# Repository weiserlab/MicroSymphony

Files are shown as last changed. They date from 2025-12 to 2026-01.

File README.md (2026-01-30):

# MicroSymphony
<a href="misc/stacked.svg">
  MicroSymphony stacked boards
</a>

MicroSymphony is a modular multi-microcontroller platform designed for **compute-first microwatt systems**. Instead of relying on a single MCU to multiplex sensing, computation, and communication, MicroSymphony physically distributes these roles across multiple ultra-low-power microcontrollers that operate concurrently while remaining power- and clock-isolated.

At its core, the platform enables predictable concurrency under tight energy budgets. Each board integrates multiple independent MCUs, a lightweight mechanism for programming them from a single host connection, and a inter-processor communication substrate built on shared non-volatile memory. This architecture avoids the timing conflicts, interrupt interference, and memory pressure inherent in monolithic single-MCU designs, while remaining simple enough for microwatt-class devices.

## Repository Structure

- [`hardware/`](https://github.com/weiserlab/MicroSymphony/tree/main/hardware)  
  Schematics, PCB designs, and platform documentation (under consturction) for the MicroSymphony multi-MCU platform.

- [`Vega_Bootloader/`](https://github.com/weiserlab/MicroSymphony/tree/main/Vega%20Bootloader#vega-bootloader)  
  The Vega programming framework, which repurposes a shared UART bus to enable low-latency programming of multiple microcontrollers from a single host interface. It supports both broadcast and individually addressed firmware updates without requiring per-MCU debug probes.

- [`IPC/`](https://github.com/weiserlab/MicroSymphony/tree/main/IPC#ipc)  
  The inter-processor communication layer that coordinates independent MCUs using a shared FRAM-based mailbox abstraction with explicit arbitration. This design provides deterministic, low-overhead communication suitable for intermittent and energy-constrained operation.

- [`Applications/`](https://github.com/weiserlab/MicroSymphony/tree/main/Applications)
  Applications designed using MicroSymphony framework. (Will be updated with more soon)

## Scope

This repository focuses on the **platform, programming, and communication mechanisms** required to build and experiment with multi-microcontroller systems at microwatt power levels. The work is under active development

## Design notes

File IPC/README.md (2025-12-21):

# IPC

Multi-MCU inter-process communication system using shared SPI FRAM with hardware-based lock arbitration.

## Features

- **Shared FRAM access**: Single external SPI FRAM shared among multiple MCUs
- **Hardware arbitration**: Dedicated REQ/GNT protocol ensures exclusive FRAM access
- **Mailbox-based messaging**: Fixed-size message slots with per-node ring buffers
- **Bulk transfers**: Efficient batch operations for sending multiple messages
- **Scalable architecture**: Supports 1 arbiter and multiple workers (tested upto 3 workers)

## File Structure

```
.
├── SPI_Arbitrar_5969/       # Arbiter (master) MCU code
│   ├── main.c               # Arbiter logic, REQ/GNT handling
│   ├── fram.c/h             # FRAM SPI driver (arbiter side)
│   ├── mailbox.c/h          # Mailbox management
│   ├── uart.c/h             # UART debug interface
│
└── SPI_Worker_5969/         # Worker node MCU code
    ├── main.c               # Worker logic, lock acquisition
    ├── fram.c/h             # FRAM SPI driver (worker side)
    ├── mailbox.c/h          # Mailbox operations
    └── uart.c/h             # UART debug interface
```

## Wiring and Connections

### MCU
- This wiring is for **MSP430FR5969**, pin mapping have to be changed for MSP430FR5949

### SPI Bus (UCB0) - Shared by All MCUs
| Signal | Pin  | Description |
|---|---|---|
| MOSI | P1.6 | Master Out Slave In |
| MISO | P1.7 | Master In Slave Out |
| SCK | P2.2 | SPI Clock |
| CS# | P1.5 | FRAM Chip Select |

### REQ/GNT Pairs (Arbiter ↔ Workers)

**Arbiter Pins:**

| Worker | REQ (Input) | GNT (I/O) | Description |
|---|---|---|---|
| Node 1 | P1.4 | P1.3 | Request/Grant for Node 1 |
| Node 2 | P1.2 | P3.0 | Request/Grant for Node 2 |
| Node 3 | P3.5 | P3.6 | Request/Grant for Node 3 |

**Worker Pins (same for all workers):**

| Signal | Pin  | Description |
|---|---|---|
| REQ | P1.4 | Request line to arbiter |
| GNT | P1.3 | Grant line from arbiter |

### Protocol
- Default state: Pull-down (logic 0)
- Signaling: Brief HIGH pulses
- Interrupts: Triggered on low→high edges
- Only one MCU accesses FRAM at a time, enforced by the lock protocol

## Usage

### Lock Management

```c
lock_acquire()
```
Requests and acquires exclusive access to the shared FRAM. Worker sends REQ pulse and waits for GNT from arbiter.

```c
lock_release()
```
Releases the FRAM lock so that other nodes can access it. Worker sends REQ pulse to signal release.

### Mailbox Operations

<a href="../misc/mailbox.svg">
  MicroSymphony mailbox layout
</a>

**All mailbox operations must be performed while holding the FRAM lock.**

```c
mailbox_send_msg(dest, src, buf, len)
```
Enqueues a single message of length `len` from `src` into the mailbox of node `dest`.
- `dest`: Destination node index (0-3)
- `src`: Source node ID
- `buf`: Message payload buffer
- `len`: Payload length (≤ 60 bytes)
- Returns: 1 on success, 0 on failure

```c
mailbox_send_bulk(dest, src, buf, total_len)
```
Sends bulk data from `src` to node `dest` using an optimized FRAM write.
- `dest`: Destination node index (0-3)
- `src`: Source node ID
- `buf`: Data buffer
- `total_len`: Total data length
- Returns: 1 on success, 0 on failure

```c
mailbox_recv_msg(id, src_out, len_out, buf)
```
Dequeues the next message for node `id` and returns its source and payload.
- `id`: This node's index
- `src_out`: Pointer to store source node ID
- `len_out`: Pointer to store payload length
- `buf`: Buffer to receive payload (≥ 60 bytes)
- Returns: 1 on success, 0 if mailbox empty

## Notes

- **FRAM Layout**: 4 mailboxes @ 20 kB each, starting at `0x01000`, `0x06000`, `0x0B000`, `0x10000`
- **Message Slots**: Fixed 64-byte slots (4-byte header + 60-byte payload max)
- **Notification Mechanism**: Global FRAM byte (`0x00010`) tracks which nodes have pending messages
- **Initialization**: Call `mailbox_init_layout()` once during system setup to initialize all mailbox descriptors
- **Node Configuration**: Workers must set `NODE_ID` (1-3) during compilation
- **UART Debug**: Both arbiter and workers support UART output on P2.0 (TX) / P2.1 (RX) for debugging

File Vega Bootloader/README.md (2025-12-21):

# Vega Bootloader

The **Vega Bootloader** is a custom bootloader designed as part of the **MicroSymphony** platform to enable broadcast-based firmware upgrades for multiple microcontrollers using a single programmer. This bootloader can be loaded onto MSP430-class microcontrollers, with code provided for MSP430FR5949/5969/5959. 

The bootloader is built on [MSP430FRBoot](https://www.ti.com/lit/an/slaa721e/slaa721e.pdf), TI's bootloader framework.

## Overview

In this system:
- **Target**: The microcontroller(s) that receive the bootloader and will be programmed over the multi-drop network
- **Host**: An external microcontroller (MSP430FR5969 LaunchPad) that serves as the programmer, flashing firmware to all connected targets simultaneously

<a href="../misc/bootloader_flow.svg">
  VEGA Bootloader Flow
</a>

## Features

- **GPIO-based boot entry**: Boot pin based entry mechanism into boot mode on reset
- **Unique addressing**: Each microcontroller has an address in format `xxxyyyy` where:
  - `xxx` = board/platform number (one-hot encoded)
  - `yyyy` = microcontroller number (one-hot encoded)
- **Multi-drop UART protocol**: Enables broadcasting to multiple targets
- **Simultaneous flashing**: Flash multiple microcontrollers at once (tested up to 12 devices)
- **Built on MSP430FRBoot**: Leverages TI's proven bootloader framework

## Prerequisites

- Code Composer Studio (CCS) IDE
- MSP430FR5969 LaunchPad (for Host)
- MSP430FR5949/5969/5959 targets
- Python 3.6+ with `pyserial` library

## Repository Structure

```
.
├── Host-parallel/              # Host MSP430FR5969 project (CCS project)
├── MSPFR5949/
│   ├── App1_5949/             # Example application for MSP430FR5949 (CCS project)
│   └── Slave-parallel_5949/   # Bootloader for MSP430FR5949 (CCS project)
├── send2MSP-parallel.py       # Python script to send app image to host
└── README.md                  # This file
```

## Hardware Connections

### Host MSP (MSP430FR5969 LaunchPad)
- **P2.6** → RX (UART receive)
- **P2.5** → TX (UART transmit)
- **P3.0** → RST (reset line to all targets)
- **P1.3** → Boot pin (connects to all targets)

### Target MSP (MSP430FR5949/5969/5959)
- **P2.6** → RX (UART receive)
- **P2.5** → TX (UART transmit)
- **RST** → RST (shared reset line from host)
- **P1.3** → Boot pin (from host's P1.3)

All devices (host and targets) must share a common ground connection.

## Getting Started

<a href="../misc/flashing_flow.svg">
  VEGA Bootloader Flow
</a>

### Step 1: Flash the Bootloader to Target Devices

1. **Configure the bootloader** for each target:
   - Open the appropriate `Slave-parallel_xxxx` project for your target MCU in CCS
   - Edit `TI_MSPBoot_Config.h` to set:
     - `SLAVE_ADDRESS_MASK`: Unique address for this target (e.g., `BIT0`, `BIT1`, `BIT2`, `BIT3`)
     - `BOARD_ADDRESS_MASK`: Board/platform number (e.g., `BIT4`, `BIT5`, `BIT6`)
     - `HW_ENTRY_CONDITION`: Boot pin configuration (default: `P1IN & BIT3`)
   
   **Important**: Ensure no two targets have the same address combination! If addresses conflict, multiple devices may respond simultaneously, causing communication errors and flash failures.

2. **Build and flash** the bootloader project to each target microcontroller using CCS or a programmer

3. **Repeat** for all target devices, changing the address for each

### Step 2: Prepare Your Application

1. **Merge your application code** into the appropriate `App1_xxxx` project for your target MCU

2. **Configure the linker file**:
   - The App project should use the `lnk_App.cmd` linker file
   - This ensures the application is placed in the correct memory region (not overwriting the bootloader)

3. **Build the application** in CCS:
   - Build the project to generate the output files
   - Locate the generated `.txt` file (TI-TXT format) in the output directory

4. **Note the TI-TXT file location** - you'll need this for the Python script

### Step 3: Flash the Host Programmer

1. **Open** the `Host-parallel` project in CCS

2. **Verify memory addresses** in `main.c` match your target device (see [Linker File Generation](#linker-file-generation) if adapting to other MSP variants)

3. **Build and flash** the Host project to the MSP430FR5969 LaunchPad

### Step 4: Program Targets via Host

1. **Connect hardware**:
   - Connect the Host MSP430FR5969 LaunchPad to your PC via USB
   - Ensure all target devices are connected to the host as described in [Hardware Connections](#hardware-connections)

2. **Configure the Python script**:
   - Open `send2MSP-parallel.py`
   - Set `port_path` to match your serial port:
     - Linux: `/dev/ttyACM0`, `/dev/ttyACM1`, or `/dev/ttyUSB0`
     - Windows: `COM3`, `COM4`, etc.
     - macOS: `/dev/cu.usbmodem*` (e.g., `/dev/cu.usbmodem14201`)
   
   ```python
   port_path = "/dev/ttyACM0"  # Change to your port
   ```

3. **Run the flashing script**:
   ```bash
   python send2MSP-parallel.py
   ```

4. The script will:
   - Parse the TI-TXT file
   - Frame the data into packets
   - Send the firmware image to the host
   - The host will broadcast to all connected targets
   - Targets matching the configured addresses will be programmed

## Troubleshooting

- **Targets not responding**: Verify all addresses are unique and connections are correct
- **Flash verification fails**: Ensure the application doesn't overlap with bootloader memory
- **Serial port errors**: Check port permissions and that the correct port is specified
- **CRC mismatch**: Regenerate the TI-TXT file and ensure no corruption during transfer

## References

- [MSP430FRBoot Application Note (SLAA721E)](https://www.ti.com/lit/an/slaa721e/slaa721e.pdf)
- [MSP430FR5xx and MSP430FR6xx Family User's Guide](https://www.ti.com/lit/ug/slau367p/slau367p.pdf)
- Code Composer Studio: [https://www.ti.com/tool/CCSTUDIO](https://www.ti.com/tool/CCSTUDIO)

See individual source files for license information. This project builds upon TI's MSP430FRBoot framework.

This is part of the MicroSymphony platform research project. For questions or contributions, please open an issue.

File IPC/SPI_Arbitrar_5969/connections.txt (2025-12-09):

SPI: UCB0 on all MCUs (arbiter + workers)

MOSI: P1.6

MISO: P1.7

SCK: P2.2

FRAM CS: moved to P2.3 (to free P3.0 for Node2 GNT as you requested).

If your hardware still uses P3.0 for CS, either rewire or revert that macro yourself.

REQ/GNT logic:

Default state: pull-down, logic 0.

Pulses: drive HIGH briefly.

Interrupts: edges are low→high.

Pin mapping on arbiter (master):

Node 1:

REQ1: P1.4 (input, pulldown, interrupt)

GNT1: P1.3 (I/O, pulldown, interrupt for reset)

Node 2:

REQ2: P1.2 (input, pulldown, interrupt)

GNT2: P3.0 (I/O, pulldown, interrupt for reset)

Node 3:

REQ3: P3.5 (input, pulldown, interrupt)

GNT3: P3.6 (I/O, pulldown, interrupt for reset)

On each worker, the local pins to arbiter are always:

REQ: P1.4

GNT: P1.3

One “notification byte” in FRAM:

Address chosen as FRAM_NOTIFY_ADDR 0x0000.

Bit k set → “node with index k has new messages”.

Mapping from bit index → node ID is done in arbiter.

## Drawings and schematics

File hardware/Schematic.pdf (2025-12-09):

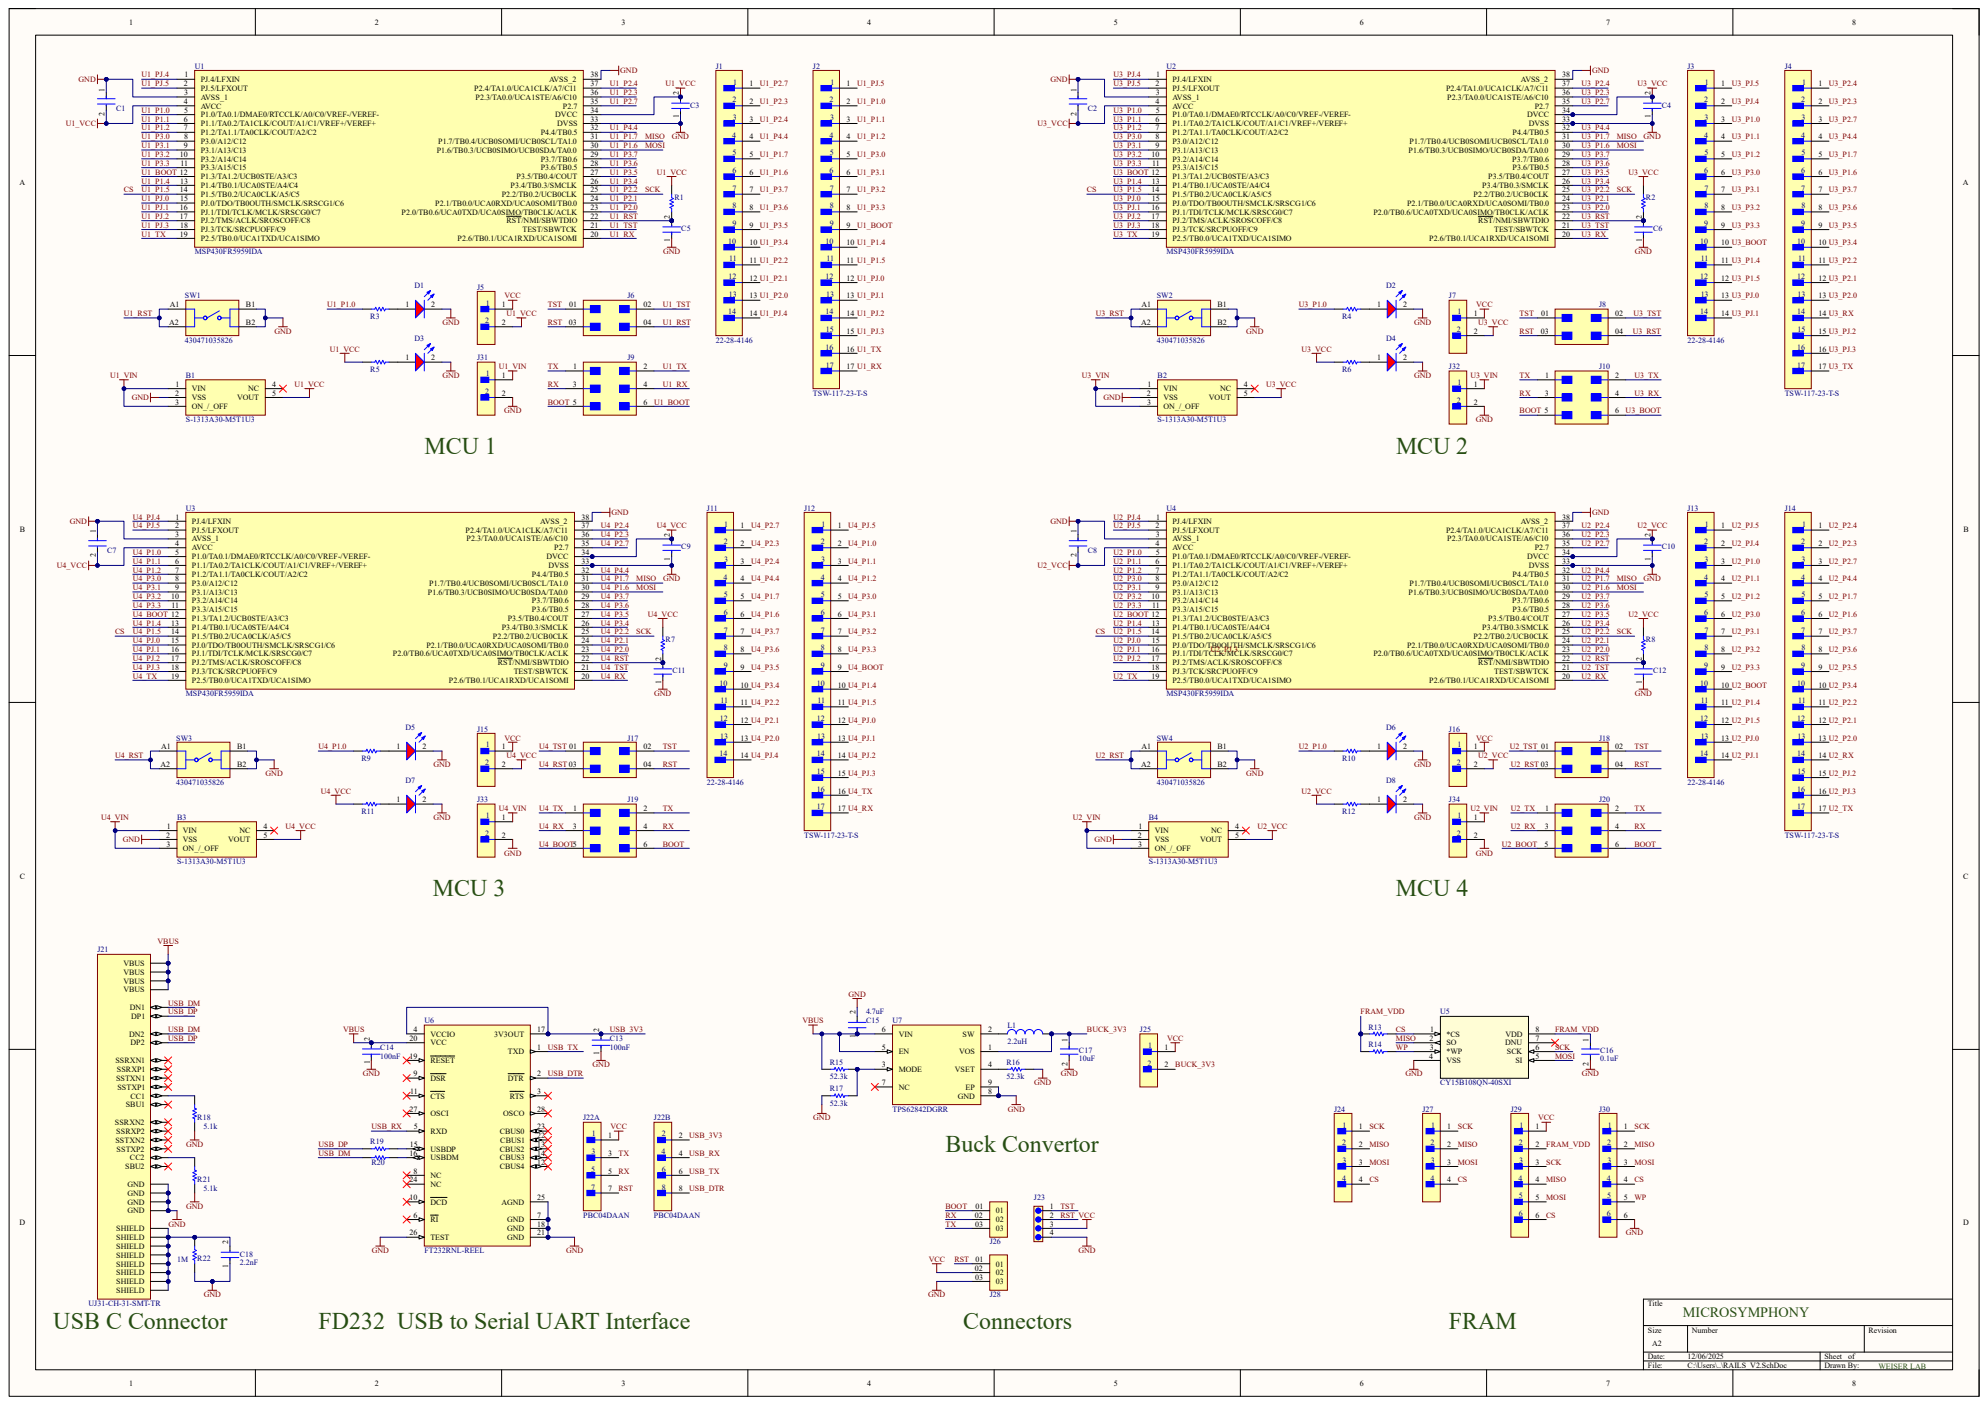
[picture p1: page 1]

P1.5/TB0.2/UCA0CLK/A5/C5 14
PJ.0/TDO/TB0OUTH/SMCLK/SRSCG1/C6 15
PJ.1/TDI/TCLK/MCLK/SRSCG0/C7 16
PJ.2/TMS/ACLK/SROSCOFF/C8 17

PJ.3/TCK/SRCPUOFF/C9 18

FD232 USB to Serial UART Interface

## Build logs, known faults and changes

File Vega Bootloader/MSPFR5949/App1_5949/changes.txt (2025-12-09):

- Folder properties -> General -> Device variant -> __MSP430FR5959__
- replace .cmd file generated from Utilities/linkerGen in Config_App
- remove .cmd in / if genearted to remove 100+ errors during compilation

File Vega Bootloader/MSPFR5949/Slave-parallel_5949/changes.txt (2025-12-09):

- add 38400 baud

Linkers generated on 3/10/2025:

output_filename:  lnk_fr5949_single_2k_xxx.cmd
lnk_filename:  lnk_msp430fr5949.cmd
boot_size:  0xc00
Device name:  msp430fr5949
2025-10-03

App start:     0x4400
appl_end_addr: 0xf3ff
Flex start:    0x10000
flex_end_addr: 0xf400
vector_addr:      0xf390
The two linker files for boot side and application side are generated!

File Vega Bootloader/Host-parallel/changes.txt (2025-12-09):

in main.c:
change static uint32_t App_EndAddress_Upper = 0x13FFF - 8; // -8 for MSP5959

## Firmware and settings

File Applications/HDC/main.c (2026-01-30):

#include <msp430.h>
#include <stdint.h>
#include <string.h>

#include "uart.h"
#include "fram.h"
#include "mailbox.h"
#include "worker.h"
#include "hypercam_full_256.h"     // <--- 256/512/768 HV table

/* ================================================================
 * CONFIGURATION
 * ================================================================ */

/* Total cooperating MCUs */
#define N_NODES       3u      /* change to 3 or 4 later */

/* Node ID: 0 .. N_NODES-1 (set individually per build) */
#define NODE_ID       0u

/* MNIST image size */
#define IMG_W         28u
#define IMG_H         28u
#define NUM_PIXELS    (IMG_W * IMG_H)

/* Bits per node slice */
#define BITS_PER_NODE   (HV_DIM_BITS / N_NODES)
#define WORDS_PER_NODE  (BITS_PER_NODE / 32u)
#define BYTES_PER_NODE  (BITS_PER_NODE / 8u)

/* Accumulator type */
typedef int16_t acc_t;

// declare external HV tables
extern const uint32_t X0_words[WORDS_PER_HV];
extern const uint32_t value_hv[256][WORDS_PER_HV];
extern const uint32_t class_hv[NUM_CLASSES][WORDS_PER_HV];
extern const uint8_t sample_image[NUM_PIXELS];
// extern

uint32_t  e1, e2, e3;


void timer_start(void){
    TA0CTL = TASSEL__SMCLK | MC__CONTINUOUS | TACLR | ID__8;  // SMCLK/8
    TA0EX0 = TAIDEX_7;   
}


/* ================================================================
 * COMMUNICATION STUBS (YOU FILL THESE)
 * ================================================================ */

/* Now takes uint8_t* slice (BYTES_PER_NODE bytes) */
static void send_hv_slice_to_node0(const uint8_t *slice)
{
    /* TODO: send BYTES_PER_NODE bytes to node 0 (SPI/UART/mailbox) */
    lock_acquire();
    uint8_t resp=0;
    resp = mailbox_send_bulk(0u, NODE_ID, slice, BYTES_PER_NODE);
    // __delay_cycles(40000); // small delay (switch to level based)
    // uart0_println("Send failed");
    lock_release();
    if (!resp) {P4OUT |= BIT6; P1OUT |= BIT0;}

}

#if NODE_ID == 0
/* Now receives uint8_t* slice (BYTES_PER_NODE bytes) */
static uint8_t recv_hv_slice_from_node(uint8_t *src, uint8_t *dst)
{
    /* TODO: receive BYTES_PER_NODE bytes from node src */
    lock_acquire();
    uint16_t len = 0u;
    uint8_t resp = 1;
    resp = mailbox_recv_msg(0u, src, &len, dst);

    lock_release();
    return resp;
}
#endif


/* ================================================================
 * BIT HELPERS (LOCAL SLICE ONLY)
 * ================================================================ */

static uint8_t get_bit(const uint32_t *words, uint16_t bit)
{
    uint16_t w = bit / 32u;
    uint16_t b = bit % 32u;
    return (words[w] >> b) & 1u;
}

/* Rotate the FULL HV (all WORDS_PER_HV words) left by 1 bit.
 * This matches the Python / training rotation, independent of node split.
 */
static void rotate_left1_full(uint32_t *words)
{
    uint32_t carry = 0, next = 0;
    uint16_t i;
    for (i = 0; i < WORDS_PER_HV; i++)
    {
        next = (words[i] >> 31) & 1u;
        words[i] = (words[i] << 1) | carry;
        carry = next;
    }
    /* wrap-around bit */
    if (carry)
        words[0] |= 1u;
}


/* ================================================================
 * GET GLOBAL SLICE OFFSET FOR THIS NODE
 * ================================================================ */

static inline uint16_t global_bit_offset(void)
{
    return NODE_ID * BITS_PER_NODE;
}


/* ================================================================
 * ENCODING (HV-SPLIT)
 * ================================================================ */

/* slice_out is now uint8_t*, length BYTES_PER_NODE. */
static void encode_image_slice(const uint8_t *img,
                               uint8_t *slice_out)
{
    acc_t  acc[BITS_PER_NODE];
    /* full position HV for global rotation */
    uint32_t pos_full[WORDS_PER_HV];
    /* this node's bound slice */
    uint32_t bound[WORDS_PER_NODE];

    uint16_t i, b, k;

    // uart0_println("Encoding image slice...");

    // uart0_println("1...");
    // uart0_println("Clearing accumulator...");
    /* 1. Clear accumulator */
    for (i = 0; i < BITS_PER_NODE; i++)
        acc[i] = 0;


    /* 2. Initialize FULL position HV:
     *    Copy entire X0_words (global HV), not just this node's slice.
     */
    for (i = 0; i < WORDS_PER_HV; i++)
        pos_full[i] = X0_words[i];

    // uart0_println("Position HV full initialized.");
    /* Node's slice word offset in the full HV */
    uint16_t off = global_bit_offset() / 32u;   // word offset

    /* 3. Process each pixel */
    for (k = 0; k < NUM_PIXELS; k++)
    {
        // uart0_println("Processing pixel:");
        // uart0_print_uint(k);
        // uart0_println("");
        uint8_t v = img[k];  /* pixel 0..255 */

        /* Slice of value HV for this pixel:
         * value_hv[v] is full HV; we take this node's slice.
         * Slice of position HV for this pixel:
         * pos_full is full HV; we take this node's slice.
         */
        for (i = 0; i < WORDS_PER_NODE; i++)
            bound[i] = pos_full[off + i] ^ value_hv[v][off + i];

        /* Update acc */
        for (b = 0; b < BITS_PER_NODE; b++)
        {
            uint8_t bit = get_bit(bound, b);
            acc[b] += (bit ? 1 : -1);
        }

        /* Permute FULL position HV */
        rotate_left1_full(pos_full);
    }

    // uart0_println("Finalizing slice...");
    /* 4. Majority vote → slice_out (byte-packed) */
    for (i = 0; i < BYTES_PER_NODE; i++)
        slice_out[i] = 0;

    // uart0_println("Performing majority vote...");
    for (b = 0; b < BITS_PER_NODE; b++)
    {
        uint8_t bit = (acc[b] > 0);
        if (bit) {
            /* bit b → byte index = b/8, bit position = b%8 (LSB-first) */
            uint16_t byte_idx = b >> 3;
            uint8_t bit_pos = b & 7u;
            slice_out[byte_idx] |= (uint8_t)(1u << bit_pos);
        }
    }
}


/* ================================================================
 * NODE 0: COLLECT SLICES, FORM FINAL HV, CLASSIFY
 * ================================================================ */

#if NODE_ID == 0
static uint32_t img_hv_full[WORDS_PER_HV];

/* Now takes uint8_t* slice (BYTES_PER_NODE bytes) */
static void combine_slice(uint8_t src, const uint8_t *slice)
{
    /* dst byte offset in full HV */
    uint16_t byte_off = (uint16_t)(BYTES_PER_NODE * src);

    /* Copy raw bytes into img_hv_full (reinterpret as uint8_t*) */
    uint8_t *dst_bytes = (uint8_t *)img_hv_full;

    uint16_t i;
    for (i = 0; i < BYTES_PER_NODE; i++) {
        dst_bytes[byte_off + i] = slice[i];
    }
}

static uint8_t classify_image(void)
{
    /* Full-HV Hamming classification using class_hv[][] */

    uint32_t best = UINT32_MAX;
    uint8_t best_c = 0;

    uint8_t c;
    uint16_t i;

    for (c = 0; c < NUM_CLASSES; c++) {
        uint32_t dist = 0;
        for (i = 0; i < WORDS_PER_HV; i++) {
            uint32_t x = img_hv_full[i] ^ class_hv[c][i];

            /* 32-bit SWAR popcount (portable, efficient on MSP430 GCC) */
            x = x - ((x >> 1) & 0x55555555u);
            x = (x & 0x33333333u) + ((x >> 2) & 0x33333333u);
            uint32_t pc = (((x + (x >> 4)) & 0x0F0F0F0Fu) * 0x01010101u) >> 24;

            dist += pc;
        }
        if (dist < best) {
            best = dist;
            best_c = c;
        }
    }

    return best_c;
}
#endif


/* ================================================================
 * MAIN PROCESSING
 * ================================================================ */

// static uint8_t image_buf[NUM_PIXELS];   // Fill this with your MNIST image

static void node_run(void)
{
    uint8_t my_slice[BYTES_PER_NODE];

    /* image already loaded*/

    /* Compute this node's slice */
    // uart0_println("Computing node slice...");
    encode_image_slice(sample_image, my_slice);
    // uart0_println("Image slice encoded.");

#if NODE_ID == 0
    /* Root node keeps its own slice */
    combine_slice(0, my_slice);

    uint8_t src=0;
    uint8_t counter = 0;

    
    // uart0_println("Waiting for slice...");
    timer_start();
    e1 = TA0R;
    /* For N_NODES == 1 this loop is skipped (no remote nodes). */
    
    while (counter < (uint8_t)(N_NODES - 1u))
    {

        if (!recv_hv_slice_from_node(&src, my_slice)) {
            /* No message yet; you can spin, sleep, or just retry */
            __delay_cycles(500000u);
            continue;
        }

        /* Expect slices from nodes 1..N_NODES-1 */
        if (src != 0u && src < N_NODES) {
            // uart0_print("Received slice from node ");
            // uart0_print_uint(src);
            // // print the slice for debugging
            // uint8_t i;
            // for (i = 0; i < BYTES_PER_NODE; i++) {
            //     uart0_print_uint(my_slice[i]);
            //     uart0_print(" ");
            // }
            // uart0_println("");

            combine_slice(src, my_slice);
            counter++;
        } else {
            // uart0_print("Unexpected src=");
            // uart0_print_uint(src);
            // uart0_println("");
            ;
        }

        // __delay_cycles(16000000u);
    }

    e1 = TA0R - e1;
    /* Now img_hv_full[] contains the full HV_DIM_BITS final HV */

    timer_start();
    e2 = TA0R;
    uint8_t predicted = classify_image();
    e2 = TA0R - e2;

    // uart0_print("Predicted class: ");
    // uart0_print_uint(predicted);
    // uart0_println("");

    // uart0_print("Communication time (microseconds): ");
    // uart0_print_uint(e1*8u);
    // uart0_println("");

    // uart0_print("Classification time (microseconds): ");
    // uart0_print_uint(e2*8u);
    // uart0_println("");


#else
    /* Non-root nodes send their slice to node 0 */
    // uart0_println("Sending slice to node 0...");
    send_hv_slice_to_node0(my_slice);
    // uart0_print("Slice sent to node 0 from node ");
    // uart0_print_uint(NODE_ID);
    // uart0_println("");

#endif
    // spi_deinit();  // optional: free SPI if not needed anymore

}


/* ================================================================
 * MSP430 MAIN
 * ================================================================ */

int main(void)
{


    WDTCTL = WDTPW | WDTHOLD;

    /* TODO: clock / UART / SPI init */
    clock_init_8mhz();
    // uart0_init();
    node_gpio_init();


    PM5CTL0 &= ~LOCKLPM5;   // Disable the GPIO power-on default high-impedance mode

    spi_init();
    /* Reset pulse to arbiter (inform it we may have reset) */
    node_pulse_reset_on_gnt();


    P1OUT &= ~BIT0;
    P4OUT |= BIT6;


    __bis_SR_register(GIE);

    // uart0_println("HyperCam HDC Node Starting...");

    node_run();
    __bis_SR_register(LPM0_bits | GIE);
    
}

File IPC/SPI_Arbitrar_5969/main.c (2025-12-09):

// ======================= Arbiter (Master) =======================
//                   MSP430FR5969 (Arbiter)
//                 ---------------------------
//            /|\ |                       XIN|-
//             |  |                           | 32 kHz Crystal (optional)
//             ---|RST                    XOUT|-
//                |                           |
//                |                       P2.0|-> UART TX  (UCA0TXD, to USB-UART / PC)
//                |                       P2.1|<- UART RX  (UCA0RXD, from USB-UART / PC)
//                |                           |
//                |                       P1.6|-> FRAM SI   (UCB0SIMO, MOSI)
//                |                       P1.7|<- FRAM SO   (UCB0SOMI, MISO)
//                |                       P2.2|-> FRAM SCK  (UCB0CLK)
//                |                       P1.5|-> FRAM CS#  (chip select, active low)
//                |                           |
//                |                       P1.4|<- REQ1      (Node1 -> Arbiter, request)
//                |                       P1.3|<-> GNT1     (Arbiter <-> Node1, grant / reset)
//                |                       P1.2|<- REQ2      (Node2 -> Arbiter, request)
//                |                       P3.0|<-> GNT2     (Arbiter <-> Node2, grant / reset)
//                |                       P3.5|<- REQ3      (Node3 -> Arbiter, request)
//                |                       P3.6|<-> GNT3     (Arbiter <-> Node3, grant / reset)
//                |                           |
//                |                       P1.0|-> LED (activity / REQ seen)
//                |                       P4.6|-> LED (FRAM bus owned by some node)
//                |                           |
//               GND|---------------------------

#include <msp430.h>
#include <stdint.h>
#include "fram.h"
#include "mailbox.h"
#include "uart.h"

/* Arbiter supports 3 physical nodes for now */
#define NUM_NODES    3u

#define NODE1_ID     1u
#define NODE2_ID     2u
#define NODE3_ID     3u

/* REQ pins on arbiter */
#define N1_REQ_P1_PIN   BIT4      /* P1.4 */
#define N2_REQ_P1_PIN   BIT2      /* P1.2 */
#define N3_REQ_P3_PIN   BIT5      /* P3.5 */

/* GNT pins on arbiter */
#define N1_GNT_P1_PIN   BIT3      /* P1.3 */
#define N2_GNT_P3_PIN   BIT0      /* P3.0 */
#define N3_GNT_P3_PIN   BIT6      /* P3.6 */


/* ---- Clock ---- */

static void clock_init_8mhz(void)
{
    CSCTL0_H = CSKEY >> 8;
    CSCTL1   = DCOFSEL_6;
    CSCTL2   = SELS__DCOCLK | SELM__DCOCLK;
    CSCTL3   = DIVS__1 | DIVM__1;
    CSCTL0_H = 0;
}

/* ---- Globals ---- */

/* 0   = no one holds bus
 * 1..3 = node ID currently owning SPI/FRAM bus
 */
static volatile uint8_t g_lock_holder     = 0u;

/* Pending REQ events encoded as bits 0..(NUM_NODES-1) */
static volatile uint8_t g_req_event_mask  = 0u;

/* FCFS queue */
static volatile uint8_t g_queue[NUM_NODES];
static volatile uint8_t g_q_len           = 0u;

/* Need to schedule */
static volatile uint8_t g_need_schedule   = 0u;

/* ---- Queue helpers ---- */

static uint8_t index_to_node_id(uint8_t idx)
{
    if (idx == 0u) return NODE1_ID;
    if (idx == 1u) return NODE2_ID;
    if (idx == 2u) return NODE3_ID;
    return 0u;
}

static uint8_t queue_contains(uint8_t node_id)
{
    volatile uint8_t i;

    for (i = 0u; i < g_q_len; i++) {
        if (g_queue[i] == node_id) {
            return 1u;
        }
    }
    return 0u;
}

static void queue_push(uint8_t node_id)
{
    if (g_q_len >= NUM_NODES) {
        return;
    }
    if (queue_contains(node_id) != 0u) {
        return;
    }
    g_queue[g_q_len] = node_id;
    g_q_len++;
}

static uint8_t queue_pop(void)
{
    uint8_t i;
    uint8_t first;

    if (g_q_len == 0u) {
        return 0u;
    }

    first = g_queue[0];
    for (i = 1u; i < g_q_len; i++) {
        g_queue[i - 1u] = g_queue[i];
    }
    g_q_len--;

    return first;
}

static void queue_remove(uint8_t node_id)
{
    uint8_t i;
    uint8_t j = 0u;

    for (i = 0u; i < g_q_len; i++) {
        if (g_queue[i] != node_id) {
            g_queue[j] = g_queue[i];
            j++;
        }
    }
    g_q_len = j;
}

/* ---- GPIO init ---- */

static void arbiter_gpio_init(void)
{
    /* Port 1: N1_REQ=P1.4, N2_REQ=P1.2, N1_GNT=P1.3 */
    P1SEL0 &= ~(N1_REQ_P1_PIN | N2_REQ_P1_PIN | N1_GNT_P1_PIN);
    P1SEL1 &= ~(N1_REQ_P1_PIN | N2_REQ_P1_PIN | N1_GNT_P1_PIN);

    /* REQ inputs, pulldown, rising edge interrupt */
    P1DIR &= ~(N1_REQ_P1_PIN | N2_REQ_P1_PIN);
    P1REN |= (N1_REQ_P1_PIN | N2_REQ_P1_PIN);
    P1OUT &= ~(N1_REQ_P1_PIN | N2_REQ_P1_PIN);

    P1IES &= ~(N1_REQ_P1_PIN | N2_REQ_P1_PIN);
    P1IFG &= ~(N1_REQ_P1_PIN | N2_REQ_P1_PIN);
    P1IE  |= (N1_REQ_P1_PIN | N2_REQ_P1_PIN);

    /* GNT1 input, pulldown, rising edge for reset */
    P1DIR &= ~N1_GNT_P1_PIN;
    P1REN |= N1_GNT_P1_PIN;
    P1OUT &= ~N1_GNT_P1_PIN;
    
    P1IES &= ~N1_GNT_P1_PIN;
    P1IFG &= ~N1_GNT_P1_PIN;
    P1IE  |= N1_GNT_P1_PIN;

    /* Port 3: N3_REQ=P3.5, N2_GNT=P3.0, N3_GNT=P3.6 */
    P3SEL0 &= ~(N3_REQ_P3_PIN | N2_GNT_P3_PIN | N3_GNT_P3_PIN);
    P3SEL1 &= ~(N3_REQ_P3_PIN | N2_GNT_P3_PIN | N3_GNT_P3_PIN);

    /* REQ3 */
    P3DIR &= ~N3_REQ_P3_PIN;
    P3REN |= N3_REQ_P3_PIN;
    P3OUT &= ~N3_REQ_P3_PIN;
    
    P3IES &= ~N3_REQ_P3_PIN;
    P3IFG &= ~N3_REQ_P3_PIN;
    P3IE  |= N3_REQ_P3_PIN;

    /* GNT2, GNT3 inputs with pulldown, rising edge for reset */
    P3DIR &= ~(N2_GNT_P3_PIN | N3_GNT_P3_PIN);
    P3REN |= (N2_GNT_P3_PIN | N3_GNT_P3_PIN);
    P3OUT &= ~(N2_GNT_P3_PIN | N3_GNT_P3_PIN);

    P3IES &= ~(N2_GNT_P3_PIN | N3_GNT_P3_PIN);
    P3IFG &= ~(N2_GNT_P3_PIN | N3_GNT_P3_PIN);
    P3IE  |= (N2_GNT_P3_PIN | N3_GNT_P3_PIN);

    /* LEDs */
    P1DIR |= BIT0;
    P4DIR |= BIT6;
}

/* ---- GNT pulses ---- */

static void gnt_pulse_node(uint8_t node_id)
{
    volatile uint8_t *pdir;
    volatile uint8_t *pout;
    uint8_t port_bit;

    if (node_id == NODE1_ID) {
        pdir     = &P1DIR;
        pout     = &P1OUT;
        port_bit = N1_GNT_P1_PIN;
    } else if (node_id == NODE2_ID) {
        pdir     = &P3DIR;
        pout     = &P3OUT;
        port_bit = N2_GNT_P3_PIN;
    } else if (node_id == NODE3_ID) {
        pdir     = &P3DIR;
        pout     = &P3OUT;
        port_bit = N3_GNT_P3_PIN;
    } else {
        return;
    }

    /* Disable reset interrupt on this pin during pulse */
    if (node_id == NODE1_ID) {
        P1IE  &= (uint8_t)~port_bit;
        P1IFG &= (uint8_t)~port_bit;
    } else {
        P3IE  &= (uint8_t)~port_bit;
        P3IFG &= (uint8_t)~port_bit;
    }

    *pdir |=  port_bit;
    *pout |=  port_bit;
    __delay_cycles(50u);
    *pout &= (uint8_t)~port_bit;
    *pdir &= (uint8_t)~port_bit;

    if (node_id == NODE1_ID) {
        P1IFG &= (uint8_t)~port_bit;
        P1IE  |= port_bit;
    } else {
        P3IFG &= (uint8_t)~port_bit;
        P3IE  |= port_bit;
    }
}

/* ---- Scheduler ---- */
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
